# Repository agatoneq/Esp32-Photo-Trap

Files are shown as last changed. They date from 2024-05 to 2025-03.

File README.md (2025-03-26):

# 📷 ESP32 Photo Trap for Canon EOS 60D

This is a fully functional **motion-triggered wireless shutter system** built using **two ESP32-C3 modules**.  
It allows a Canon EOS 60D DSLR camera to take **single or burst photos** based on motion detection from PIR and Doppler sensors.

Designed for remote wildlife photography or security use cases, the system is battery-powered, weather-resistant, and coded in C++ (PlatformIO).

<p align="center">
  
  
</p>

<p align="center">
  
  
</p>

## 🧠 Features

- Motion detection via **PIR** and **Doppler radar sensors**
- Wireless communication via **WiFi UDP** between modules
- Remote triggering of the **Canon EOS 60D** camera via 2.5mm jack
- **Single shot mode** and **automatic burst mode** (3s or 10s)
- **Interrupt-based manual trigger** button
- **LED indicators** for active state, motion detection, and shot in progress
- Power-efficient design with step-down converters and sleep logic
- PCB and housing designed for ease of use in low-temperature environments

## 🔌 System Architecture

The system is built from two physical modules:
- **Main unit** (camera-side):
  - ESP32, buttons, LEDs, 2-channel relay (shutter & focus)
- **Detector unit** (sensor-side):
  - ESP32, PIR + Doppler sensors, WiFi sender
  - Powered and placed independently

## 📁 Project Structure

- `/src/main/` – Core logic for the camera-side controller
- `/src/sensor/` – Logic for motion detection and UDP data transmission
- `/schematics/` – circuit diagrams and wiring schematics for hardware setup

## 🛠️ Tools & Technologies

- PlatformIO + VS Code
- ESP32-C3 with WiFi
- PIR HC-SR501 + RCWL-0516 Doppler
- 2-channel solid-state relay (G3MB-202P)
- 9V battery + step-down converters
- C++, Arduino core

## ▶️ How to Run

1. Open the project in PlatformIO (VS Code)
2. Connect the appropriate ESP32 to your PC
3. Flash the respective firmware to:
   - `MainPart` (camera unit)
   - `MoveDetector` (sensor unit)
4. Power each unit using a 9V battery or USB
5. Connect the 2.5mm jack to your Canon EOS 60D
6. Position sensor unit and switch on both modules
7. Trigger shooting via motion or manually with buttons

## 💡 Challenges

- BLE was initially considered but replaced by WiFi due to latency
- Manual GPIO mapping and debugging for ESP32-C3
- Mechanical tuning of PIR sensitivity
- UDP-based data synchronization
- GPIO11 reconfiguration using `esptool` to gain extra I/O

## 🧑‍💻 Author

**Agata Sobczyk** – designed, implemented and debugged the system independently

## 📜 License

This is a personal hardware-software project built for individual use and experimentation.

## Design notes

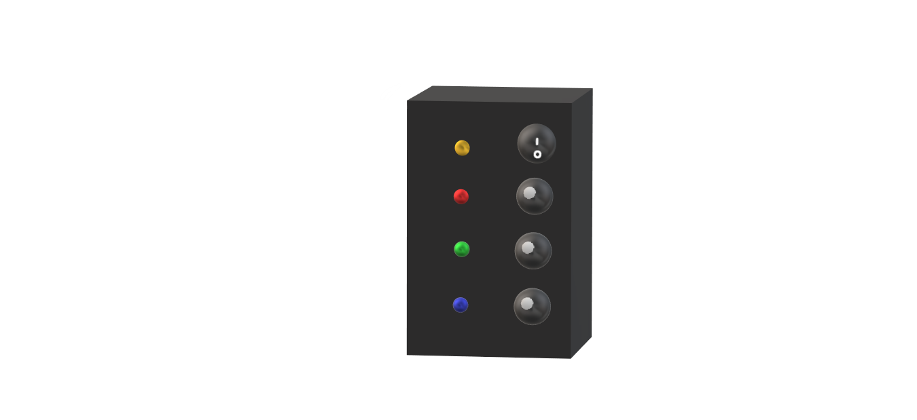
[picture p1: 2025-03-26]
schematics/Controller.png

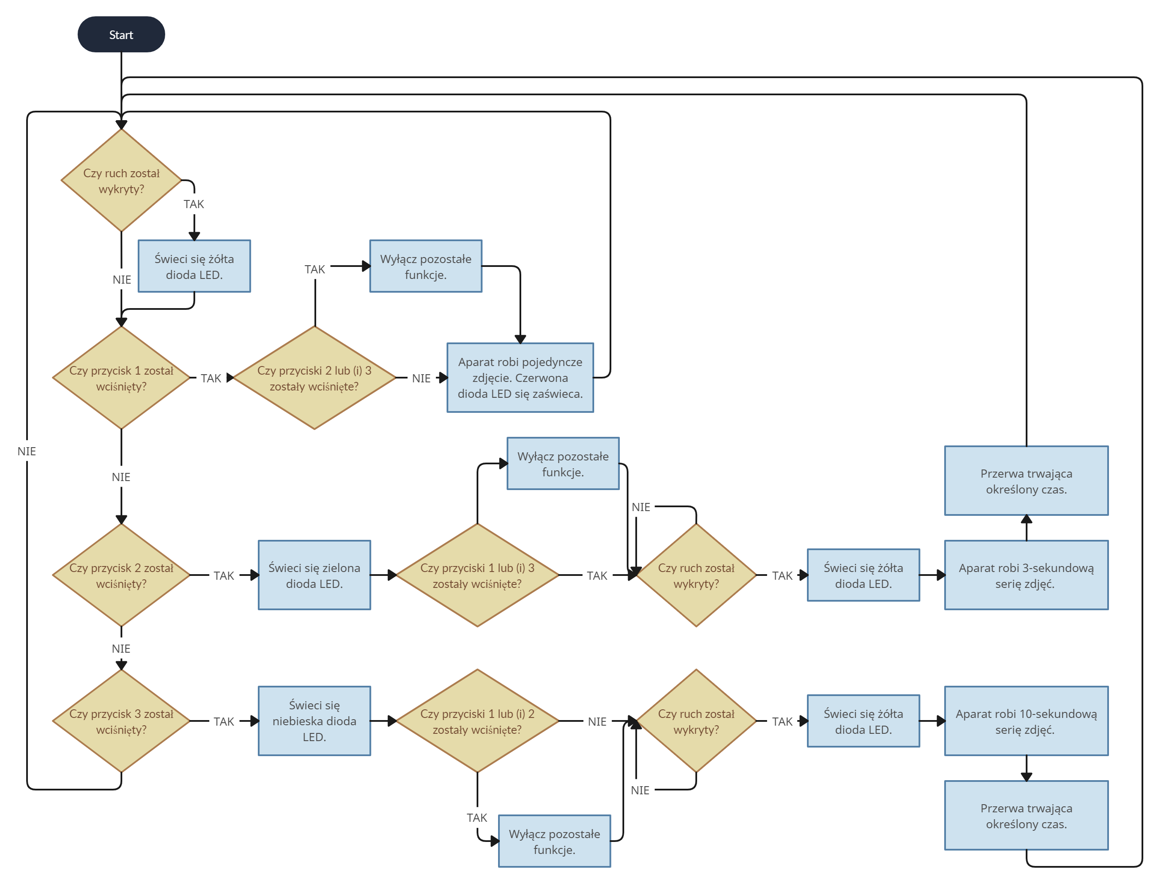
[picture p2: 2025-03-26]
schematics/SchematBlokowyDziałania.png

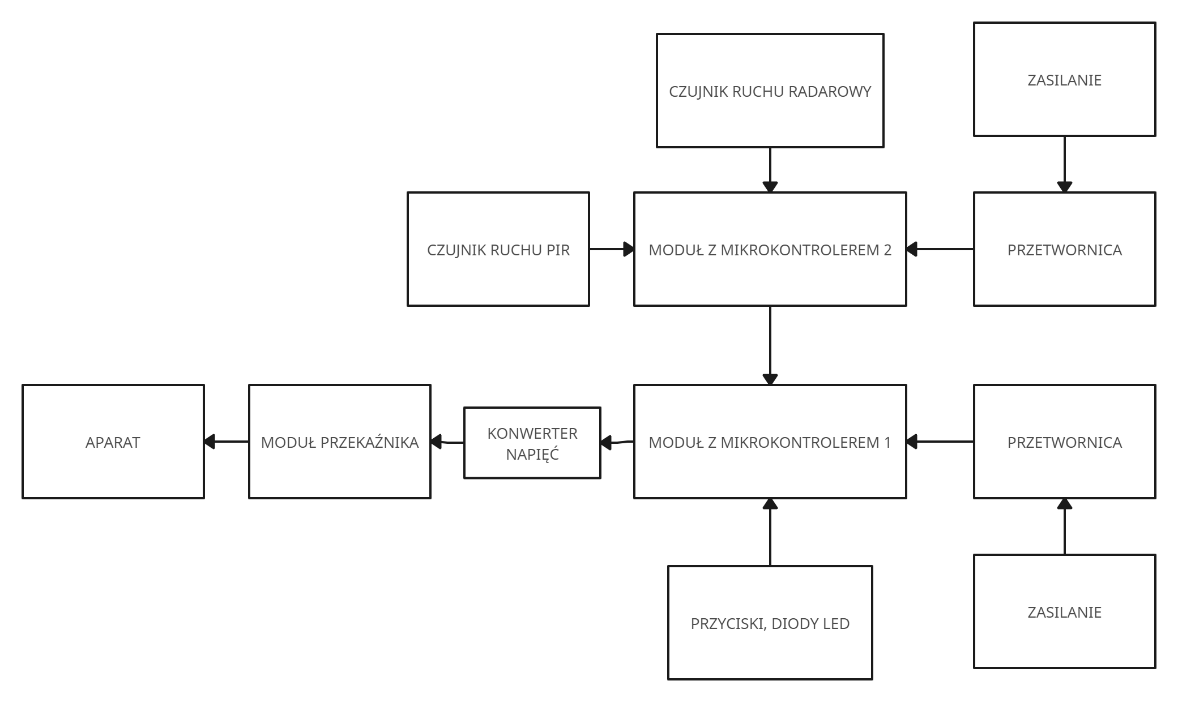
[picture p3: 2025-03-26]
schematics/SchematBlokowyUkładu.jpg

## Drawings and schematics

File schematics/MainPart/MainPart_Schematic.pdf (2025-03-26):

A

A

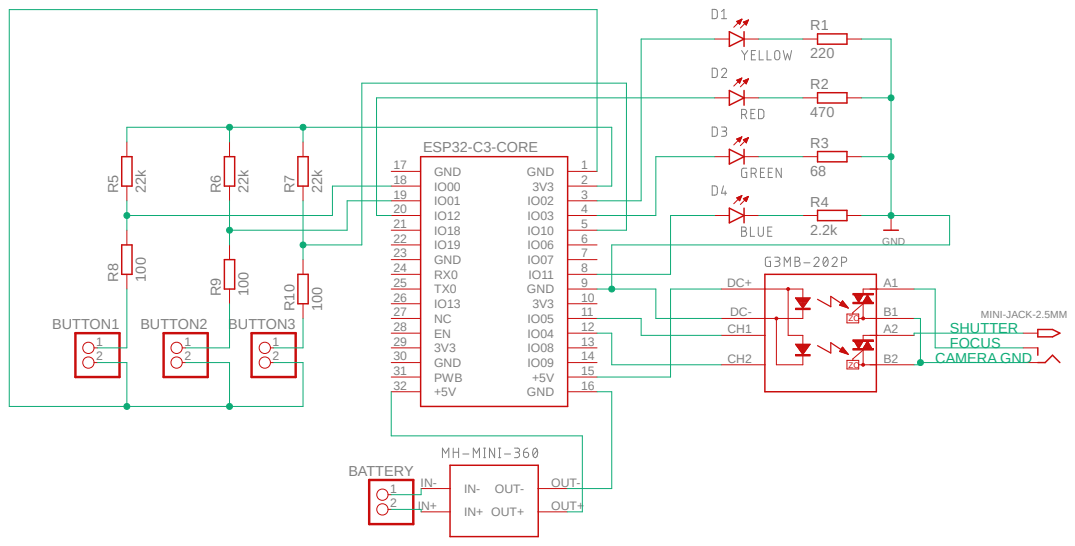
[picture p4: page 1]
2.2k ²²k; GND R1; R¹⁰; 2 BUTTON3; 2 BUTTON1; 2 BUTTON2; 2 BATTERY; MINI-JACK-2.5MM; OUT-; OUT+; GND; GND 17 IO00 18 IO01 19 IO12 20 IO18 21 IO19 22 GND 23 RX0 24 TX0 25 IO13 26 NC 27 EN 28 3V3 29 GND 30 PWB 31 +5V 32; ESP32-C3-CORE; SHUTTER; CAMERA GND; FOCUS

v3.MainPart_Agata.Sobczyk

Sheet: 1/1

18.02.2024 01:06 C:\Users\agata\OneDrive\Dokumenty\EAGLE\projects\SMIW1\v3.MainPart_Agata.Sobczyk.sch (Sheet: 1/1)

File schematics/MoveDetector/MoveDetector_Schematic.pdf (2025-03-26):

A

A

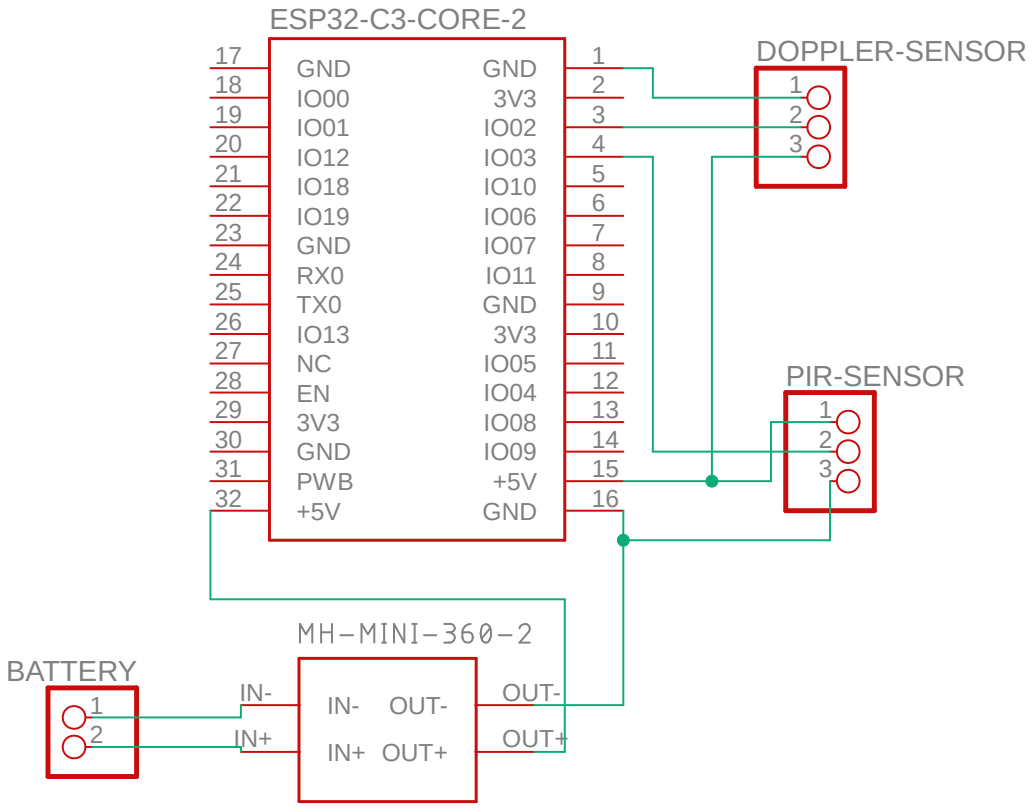
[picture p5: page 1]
2 BATTERY; 3 DOPPLER-SENSOR; 3 PIR-SENSOR; GND; GND 17 IO00 18 IO01 19 IO12 20 IO18 21 IO19 22 GND 23 RX0 24 TX0 25 IO13 26 NC 27 EN 28 3V3 29 GND 30 PWB 31 +5V 32; ESP32-C3-CORE-2; OUT-; OUT+

v3.MoveDetector_Agata.Sobczyk

Sheet: 1/1

18.02.2024 01:32 C:\Users\agata\OneDrive\Dokumenty\EAGLE\projects\SMIW1\v3.MoveDetector_Agata.Sobczyk.sch (Sheet: 1/1)

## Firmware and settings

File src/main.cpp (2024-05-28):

#include <Arduino.h>
#include <WiFi.h>
#include <WiFiUdp.h>

void pressButton1();
void pressButton2();
void pressButton3();
void mode2();
void mode3();
bool detectMove();
void takePhotos(int time);
void handleButtonInterrupt();
void takeOnePhoto();

#define button1 00
#define button2 01
#define button3 10
#define yellowLED 02
#define redLED 12
#define greenLED 03
#define blueLED 11
#define ssrCH1Focus 05
#define ssrCH2Shutter 04

const char *ssid = "esp32";
const char *password = "photo_trap_123";
const int udpPort = 1234;

int ssrON, ssrOFF;
const int debounceTime = 30;
int seriesTime = 3000;
byte button1LogicalState = 1;
byte button1LastLogicalState = 1;
byte button2LogicalState = 1;
byte button2LastLogicalState = 1;
byte button3LogicalState = 1;
byte button3LastLogicalState = 1;
int pirValue, dopplerValue;

bool tempB2;
bool tempB3;
volatile bool m2 = false;
volatile bool m3 = false;

int before2;
int after2;
int before3;
int after3;

WiFiUDP udp;
bool take_one = 0;

void IRAM_ATTR isr() {
  if(m2==1 || m3==1)
  {
    m2=0;
    m3=0;
    digitalWrite(greenLED, LOW);
    digitalWrite(blueLED, LOW);
  }
  else
  {
    take_one = 1;
  }
}

void setup() {
  Serial.begin(115200);

  pinMode(button1, INPUT_PULLUP);
  pinMode(button2, INPUT_PULLUP);
  pinMode(button3, INPUT_PULLUP);

  pinMode(yellowLED, OUTPUT);
  pinMode(redLED, OUTPUT);
  pinMode(greenLED, OUTPUT);
  pinMode(blueLED, OUTPUT);

  pinMode(ssrCH1Focus, OUTPUT);
  pinMode(ssrCH2Shutter, OUTPUT);

// Settings for Low trigger relay
  ssrON = LOW;
  ssrOFF = HIGH;
  digitalWrite(ssrCH1Focus, ssrOFF);
  digitalWrite(ssrCH2Shutter, ssrOFF);

  attachInterrupt(button1, isr, RISING);

  WiFi.begin(ssid, password);
  while (WiFi.status() != WL_CONNECTED) {
    delay(1000);
    Serial.println("Brak połączenia z WiFi...");
  }
  Serial.println("Połączono z WiFi");

for (int i = 0; i < 3; i++) {
    digitalWrite(redLED, HIGH);
    delay(500);
    digitalWrite(redLED, LOW);
    delay(300);
  }

  udp.begin(udpPort);
}

void loop() {
  takeOnePhoto();
  detectMove();
  mode2();
  mode3();
  pressButton2();
  pressButton3();
}

void takeOnePhoto()
{
 if (take_one == 1)
 {
  digitalWrite(redLED, LOW);
  takePhotos(100);
  take_one = 0;
 }
}

void pressButton1()
{
  button1LogicalState = digitalRead(button1);
  delay(debounceTime);

  if (button1LastLogicalState != button1LogicalState)
  {
    if (button1LogicalState == 1)
    {
         digitalWrite(redLED, LOW);
      takePhotos(100);
    }
    button1LastLogicalState = button1LogicalState;
  }
}

void pressButton2()
  {
  if(m2==1 && digitalRead(button2) == HIGH)
  {
  button2LogicalState = digitalRead(button2);

  if (button2LastLogicalState != button2LogicalState) {
    if (button2LogicalState == 1) {
      if (m2 == 1) {
        digitalWrite(greenLED, LOW);
        m2 = 0;
      }
    }
    button2LastLogicalState = button2LogicalState;
  }
  }
  else
  {
  button2LogicalState = digitalRead(button2);

  if (button2LastLogicalState != button2LogicalState) {
    if (button2LogicalState == 1) {
      if (m2 == 0) {
        digitalWrite(greenLED, HIGH);
        m2 = 1;
      }
    }
    button2LastLogicalState = button2LogicalState;
  }
  }
}

void pressButton3()
  {
  if(m3==1 && digitalRead(button3) == HIGH)
  {
  button3LogicalState = digitalRead(button3);

  if (button3LastLogicalState != button3LogicalState) {
    if (button3LogicalState == 1) {
      if (m3 == 1) {
        digitalWrite(blueLED, LOW);
        m3 = 0;
      }
    }
    button3LastLogicalState = button3LogicalState;
  //}
  }
  }
  else
  {
  button3LogicalState = digitalRead(button3);

  if (button3LastLogicalState != button3LogicalState) {
    if (button3LogicalState == 1) {
      if (m3 == 0) {
        digitalWrite(blueLED, HIGH);
        m3 = 1;
      }
    }
    button3LastLogicalState = button3LogicalState;
  }
  }
}

void mode2() {
  detectMove();
if (m2 && detectMove()) {
  before2 = digitalRead(button2);
    takePhotos(3000);
    delay(3000);
  }
}

void mode3() {
  detectMove();
  if (m3 && detectMove()) {
    before3 = digitalRead(button3);
    takePhotos(10000);
    delay(3000);
  }
}

bool detectMove()
{
    if (WiFi.status() != WL_CONNECTED){
    pirValue = 0;
    dopplerValue = 0;
  }
  
  int packetSize = udp.parsePacket();
  if (packetSize >= sizeof(int) * 2) {

    udp.read((uint8_t*)&pirValue, sizeof(pirValue));
    udp.read((uint8_t*)&dopplerValue, sizeof(dopplerValue));

    Serial.print("Odebrano dane - PIR: ");
    Serial.print(pirValue);
    Serial.print(", Doppler: ");
    Serial.println(dopplerValue);
  }


  if (pirValue==1 && dopplerValue==1)
  {
    digitalWrite(yellowLED, HIGH);
    return true;
  }
  else if (pirValue==0)
  {
    digitalWrite(yellowLED, LOW);
    return false;
  }
}

void takePhotos(int time)
{
  digitalWrite(ssrCH1Focus, ssrON);
  digitalWrite(ssrCH2Shutter, ssrOFF);
  delay(2000);
    digitalWrite(redLED, HIGH);
  digitalWrite(ssrCH2Shutter, ssrON);
  delay(time);
  digitalWrite(ssrCH1Focus, ssrOFF);
  digitalWrite(ssrCH2Shutter, ssrOFF);
    digitalWrite(redLED, LOW);
}
